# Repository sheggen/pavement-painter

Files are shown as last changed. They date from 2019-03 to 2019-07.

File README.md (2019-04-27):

# Raspberry Pi-controlled pavement painter

Pavement Painter is a Raspberry Pi controlled set of solenoids designed to print images to pavement using rain water. To use the Pavement Painter, you'll need to create the boards included in the Eagle files, as well as a few other controls. 

### WARNING:

Taking on this project is not for the faint at heart; there'll be lots of technical hiccups that you'll run into, and will have to solve on your own. There's hardware in addition to the software that you'll need to create, so get your soldering iron hot.  

## Requirements

- Raspberry Pi
- Python 3
- Everything included in requirements.txt and setup.sh (installable by running ```source setup.sh```)
- Physical boards (layouts included in the Pavement-painter directory)

## Installation

The code comes with a setup script. First do the apt-get installs listed at the beginning of the script. Then, running it should set up a Python Virtual Environment and pip install all the necessary components. Make sure the venv is activated before running the code, to ensure dependencies exist. To run the setup script, at the terminal enter ```source setup.sh```

## Usage

The code can most easily be ran at the terminal by running ```source run_at_boot.sh```. On the Pi, it is recommended that you do NOT run it using Thonny, as it causes a delay that will distort the print. At the terminal, we have yet to experience a delay in the printing outside of the physical limitations of the solenoids. 

## Modifying print parameters

Eventually parameters will be passed in through the above command. For now, though, I've placed all parameters at the ```__init__()``` method of the PavementPainter() class. Modify them and see what happens to your prints!

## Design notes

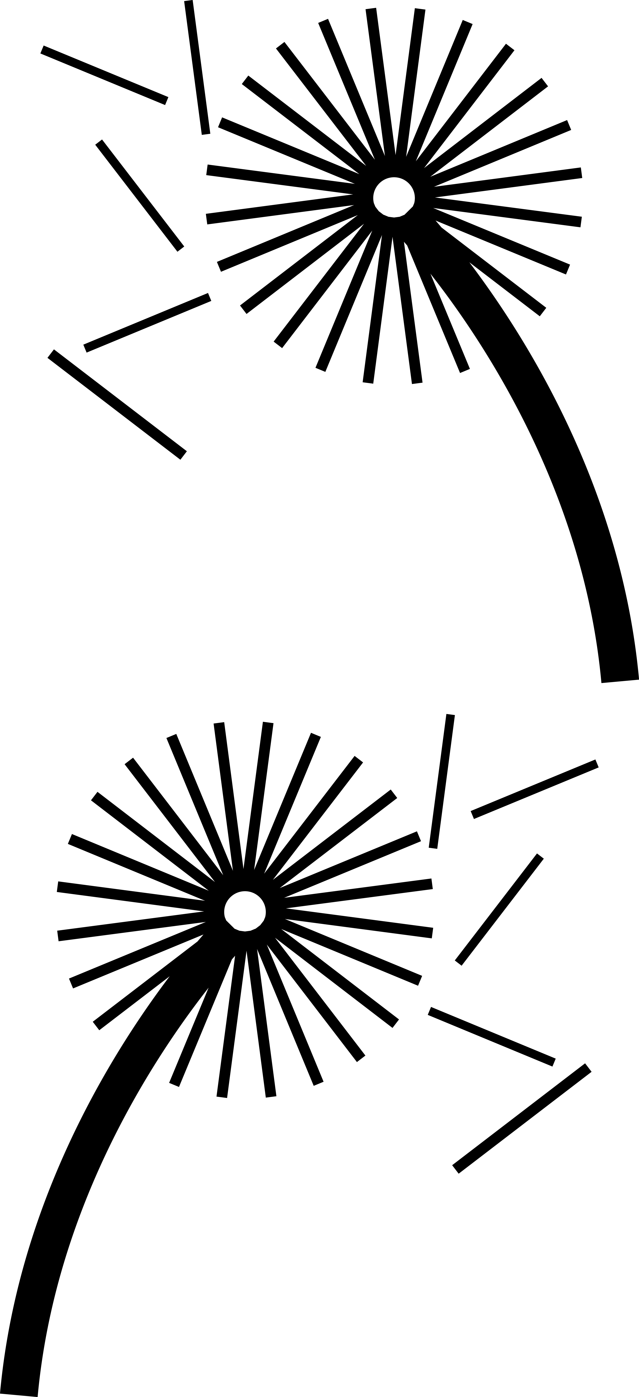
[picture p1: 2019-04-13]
webServer/app/static/images/Dandelion.jpg

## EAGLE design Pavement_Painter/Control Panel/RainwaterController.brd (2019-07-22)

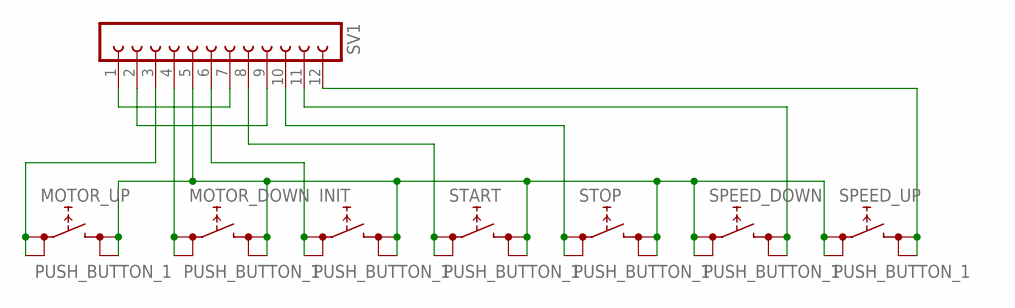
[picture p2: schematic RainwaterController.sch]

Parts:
INIT: PUSH_BUTTON_1; PUSHBUTTON
MOTOR_DOWN: PUSH_BUTTON_1; PUSHBUTTON
MOTOR_UP: PUSH_BUTTON_1; PUSHBUTTON
SPEED_DOWN: PUSH_BUTTON_1; PUSHBUTTON
SPEED_UP: PUSH_BUTTON_1; PUSHBUTTON
START: PUSH_BUTTON_1; PUSHBUTTON
STOP: PUSH_BUTTON_1; PUSHBUTTON
SV1: FE12-1; FE12

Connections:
unnamed: MOTOR_UP.P$1 (P1), MOTOR_UP.P$2 (P2), SV1.3
unnamed: SV1.1, SV1.7
unnamed: INIT.P$3 (P3), INIT.P$4 (P4), MOTOR_DOWN.P$3 (P3), MOTOR_DOWN.P$4 (P4), MOTOR_UP.P$3 (P3), MOTOR_UP.P$4 (P4), SPEED_DOWN.P$1 (P1), SPEED_DOWN.P$2 (P2), SPEED_UP.P$1 (P1), SPEED_UP.P$2 (P2), START.P$3 (P3), START.P$4 (P4), STOP.P$3 (P3), STOP.P$4 (P4), SV1.5
unnamed: SV1.2, SV1.9
unnamed: INIT.P$1 (P1), INIT.P$2 (P2), SV1.6
unnamed: START.P$1 (P1), START.P$2 (P2), SV1.8
unnamed: STOP.P$1 (P1), STOP.P$2 (P2), SV1.10
unnamed: MOTOR_DOWN.P$1 (P1), MOTOR_DOWN.P$2 (P2), SV1.4
unnamed: SPEED_DOWN.P$3 (P3), SPEED_DOWN.P$4 (P4), SV1.11
unnamed: SPEED_UP.P$3 (P3), SPEED_UP.P$4 (P4), SV1.12

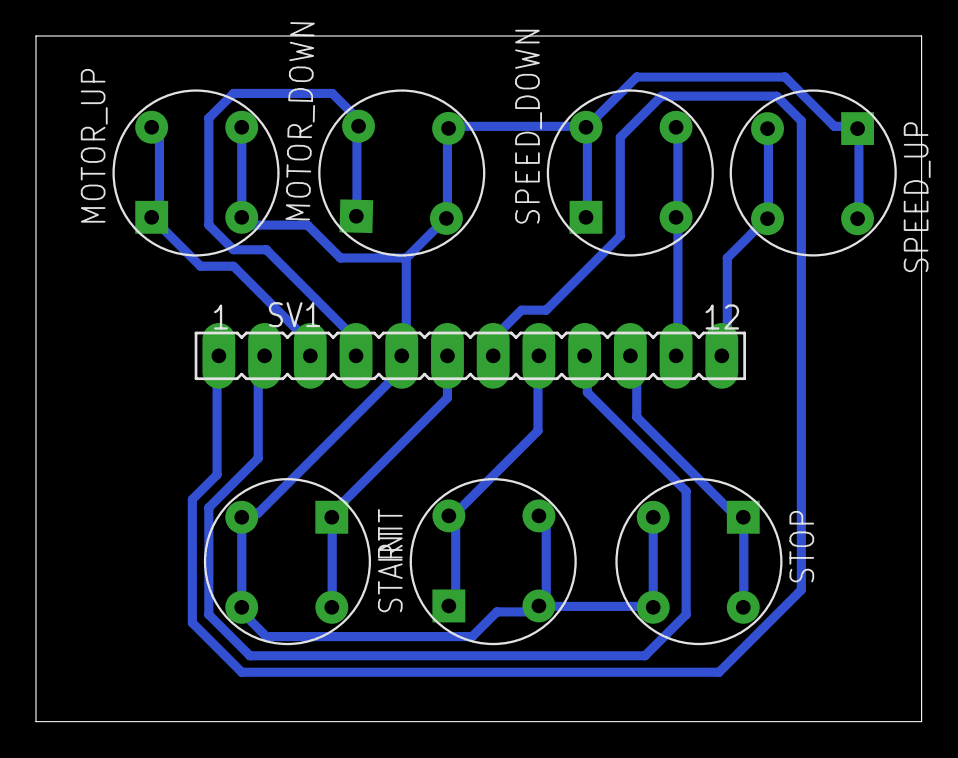
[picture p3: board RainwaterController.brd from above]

Board: 2 copper layers, 49.2 x 38.1 mm, 8 parts (0 on the bottom side), 10 nets.

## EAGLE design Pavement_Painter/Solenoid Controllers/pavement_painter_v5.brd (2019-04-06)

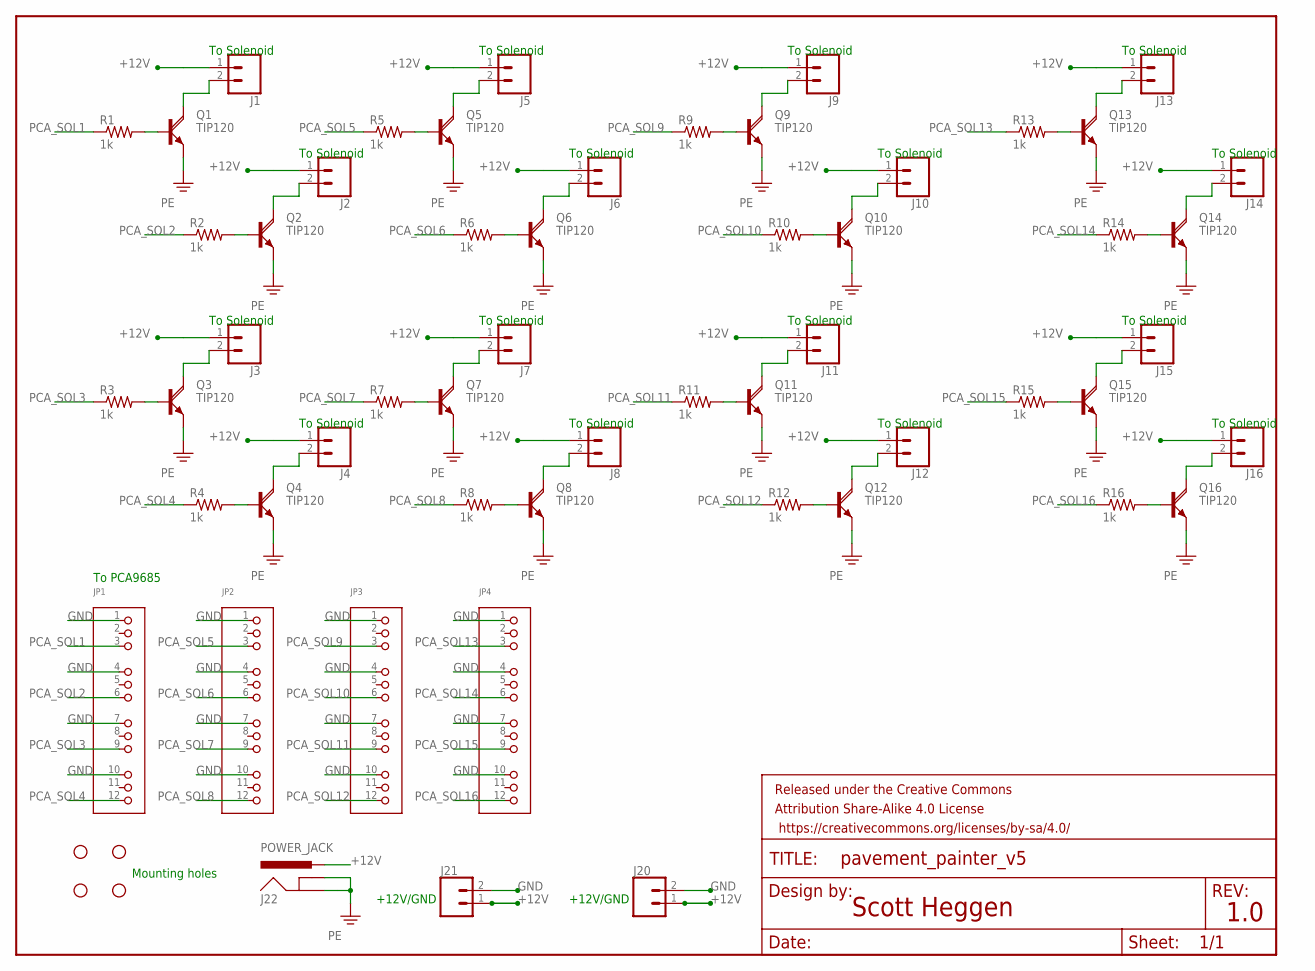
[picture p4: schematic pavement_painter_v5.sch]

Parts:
FRAME1: FRAME-LETTER; CREATIVE_COMMONS
H1, H2, H3, H4: STAND-OFF
J1, J2, J3, J4, J5, J6, J7, J8, J9, J10, J11, J12, J13, J14, J15, J16, J20, J21: CONN_02SCREWTERMINAL-200MIL-400MIL; SCREWTERMINAL-5MM-2-400MIL
J22: POWER_JACK; POWER_JACK_PTH
JP1, JP2, JP3, JP4: HEADER-3X04; 3X04
Q1, Q2, Q3, Q4, Q5, Q6, Q7, Q8, Q9, Q10, Q11, Q12, Q13, Q14, Q15, Q16: TIP120; BD679V
R1, R2, R3, R4, R5, R6, R7, R8, R9, R10, R11, R12, R13, R14, R15, R16: 1k; 0207/10

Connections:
+12V: J1.1, J2.1, J3.1, J4.1, J5.1, J6.1, J7.1, J8.1, J9.1, J10.1, J11.1, J12.1, J13.1, J14.1, J15.1, J16.1, J20.1, J21.1, J22.PWR
GND: J20.2, J21.2, J22.GND, J22.GNDBREAK, JP1.1, JP1.4, JP1.7, JP1.10, JP2.1, JP2.4, JP2.7, JP2.10, JP3.1, JP3.4, JP3.7, JP3.10, JP4.1, JP4.4, JP4.7, JP4.10, Q1.E, Q2.E, Q3.E, Q4.E, Q5.E, Q6.E, Q7.E, Q8.E, Q9.E, Q10.E, Q11.E, Q12.E, Q13.E, Q14.E, Q15.E, Q16.E
unnamed: J2.2, Q2.C
unnamed: Q2.B, R2.2
unnamed: J1.2, Q1.C
unnamed: Q1.B, R1.2
unnamed: J3.2, Q3.C
unnamed: Q3.B, R3.2
unnamed: J4.2, Q4.C
unnamed: Q4.B, R4.2
unnamed: J5.2, Q5.C
unnamed: Q5.B, R5.2
unnamed: J6.2, Q6.C
unnamed: Q6.B, R6.2
unnamed: J7.2, Q7.C
unnamed: Q7.B, R7.2
unnamed: J8.2, Q8.C
unnamed: Q8.B, R8.2
unnamed: J9.2, Q9.C
unnamed: Q9.B, R9.2
unnamed: J10.2, Q10.C
unnamed: Q10.B, R10.2
unnamed: J11.2, Q11.C
unnamed: Q11.B, R11.2
unnamed: J12.2, Q12.C
unnamed: Q12.B, R12.2
unnamed: J13.2, Q13.C
unnamed: Q13.B, R13.2
unnamed: J14.2, Q14.C
unnamed: Q14.B, R14.2
unnamed: J15.2, Q15.C
unnamed: Q15.B, R15.2
unnamed: J16.2, Q16.C
unnamed: Q16.B, R16.2
PCA_SOL1: JP1.3, R1.1
PCA_SOL2: JP1.6, R2.1
PCA_SOL3: JP1.9, R3.1
PCA_SOL4: JP1.12, R4.1
PCA_SOL5: JP2.3, R5.1
PCA_SOL6: JP2.6, R6.1
PCA_SOL7: JP2.9, R7.1
PCA_SOL8: JP2.12, R8.1
PCA_SOL9: JP3.3, R9.1
PCA_SOL10: JP3.6, R10.1
PCA_SOL11: JP3.9, R11.1
PCA_SOL12: JP3.12, R12.1
PCA_SOL13: JP4.3, R13.1
PCA_SOL14: JP4.6, R14.1
PCA_SOL15: JP4.9, R15.1
PCA_SOL16: JP4.12, R16.1

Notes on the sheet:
To Solenoid
To PCA9685
+12V/GND
Scott Heggen
1.0
Mounting holes

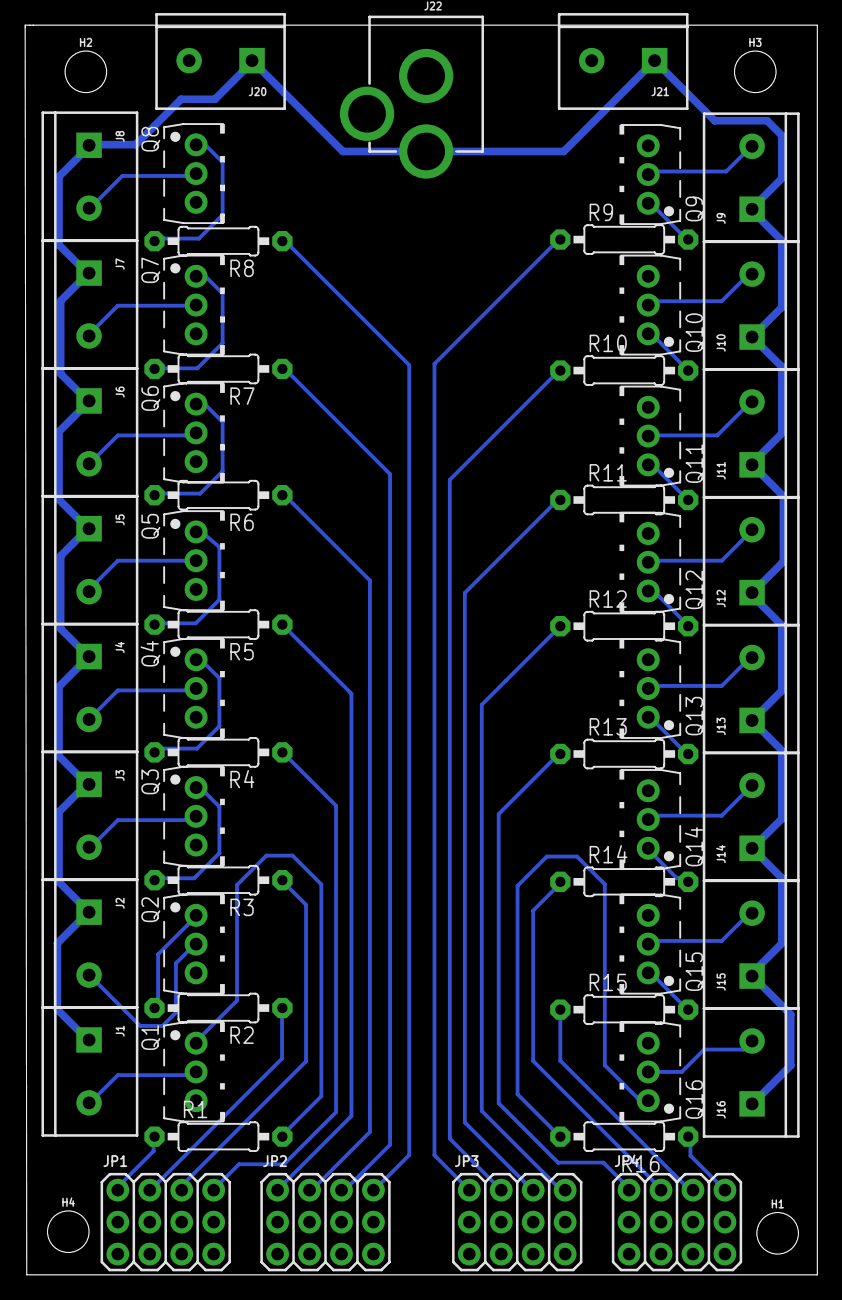
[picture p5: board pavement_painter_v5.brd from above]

Board: 2 copper layers, 63.0 x 99.3 mm, 60 parts (0 on the bottom side), 50 nets.

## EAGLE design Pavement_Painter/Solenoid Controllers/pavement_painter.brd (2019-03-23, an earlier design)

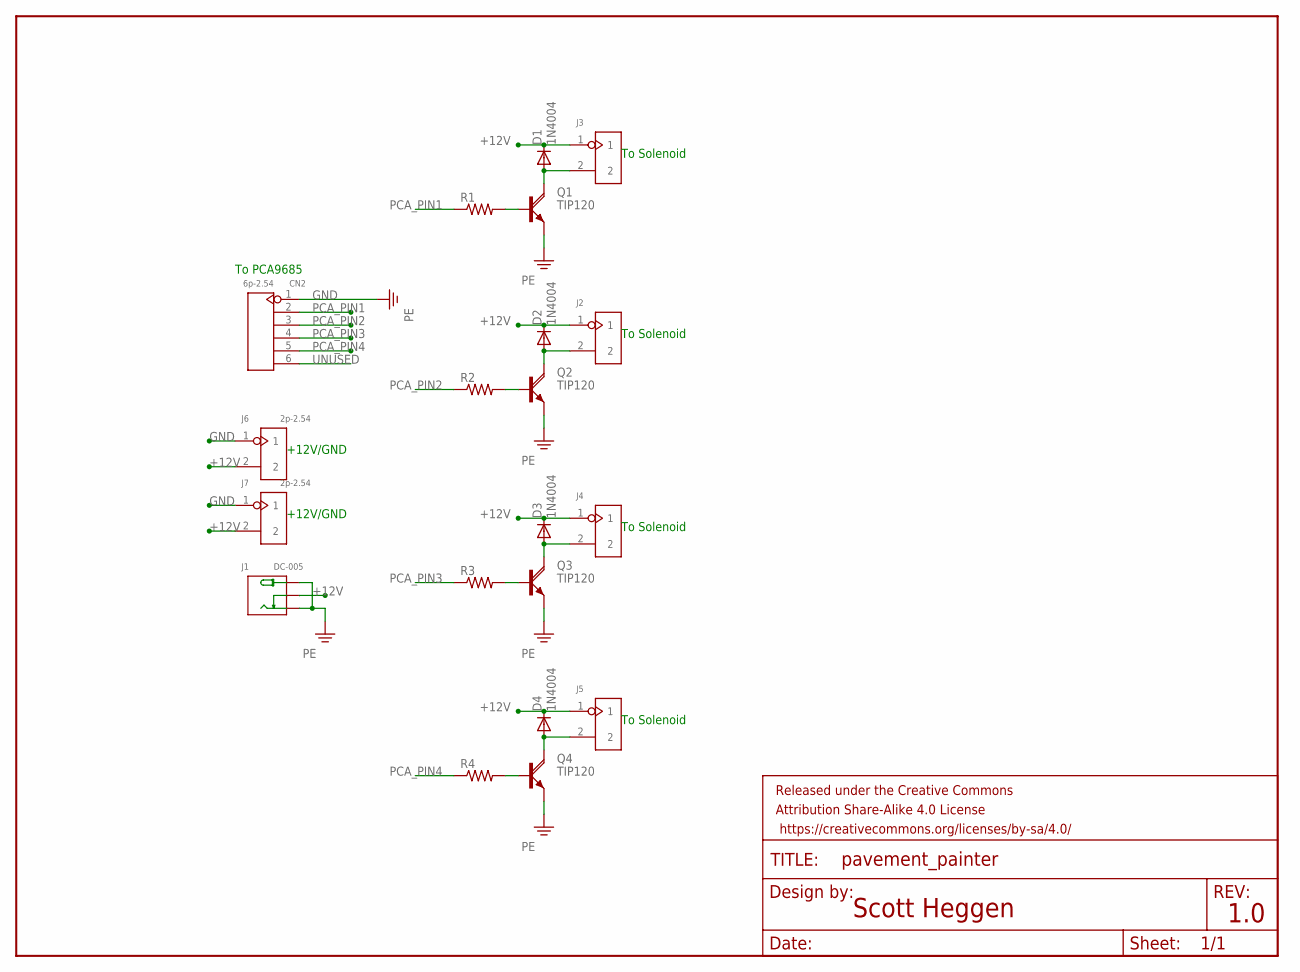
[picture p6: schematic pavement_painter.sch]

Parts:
CN2: 6p-2.54; H6-2.54
D1, D2, D3, D4: 1N4004; DO41-10
FRAME1: FRAME-LETTER; CREATIVE_COMMONS
J1: DC-005; DCJ3P-14.2X11.0X9.0MM
J2, J3, J4, J5: DIP-BLACK-JUMPER; H2-2.54
J6, J7: 2p-2.54; H2-2.54
Q1, Q2, Q3, Q4: TIP120; TO220AH
R1, R2, R3, R4: R-US_0207/12; 0207/12

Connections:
+12V: D1.C, D2.C, D3.C, D4.C, J1.-2 (CDN), J2.1, J3.1, J4.1, J5.1, J6.2, J7.2
GND: CN2.1, J1.+, J1.-1 (-), J6.1, J7.1, Q1.E, Q2.E, Q3.E, Q4.E
unnamed: D2.A, J2.2, Q2.C
unnamed: Q2.B, R2.2
unnamed: D1.A, J3.2, Q1.C
unnamed: Q1.B, R1.2
unnamed: D3.A, J4.2, Q3.C
unnamed: Q3.B, R3.2
unnamed: D4.A, J5.2, Q4.C
unnamed: Q4.B, R4.2
PCA_PIN1: CN2.2, R1.1
PCA_PIN2: CN2.3, R2.1
PCA_PIN3: CN2.4, R3.1
PCA_PIN4: CN2.5, R4.1
UNUSED: CN2.6

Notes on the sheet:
To Solenoid
To PCA9685
+12V/GND
Scott Heggen
1.0

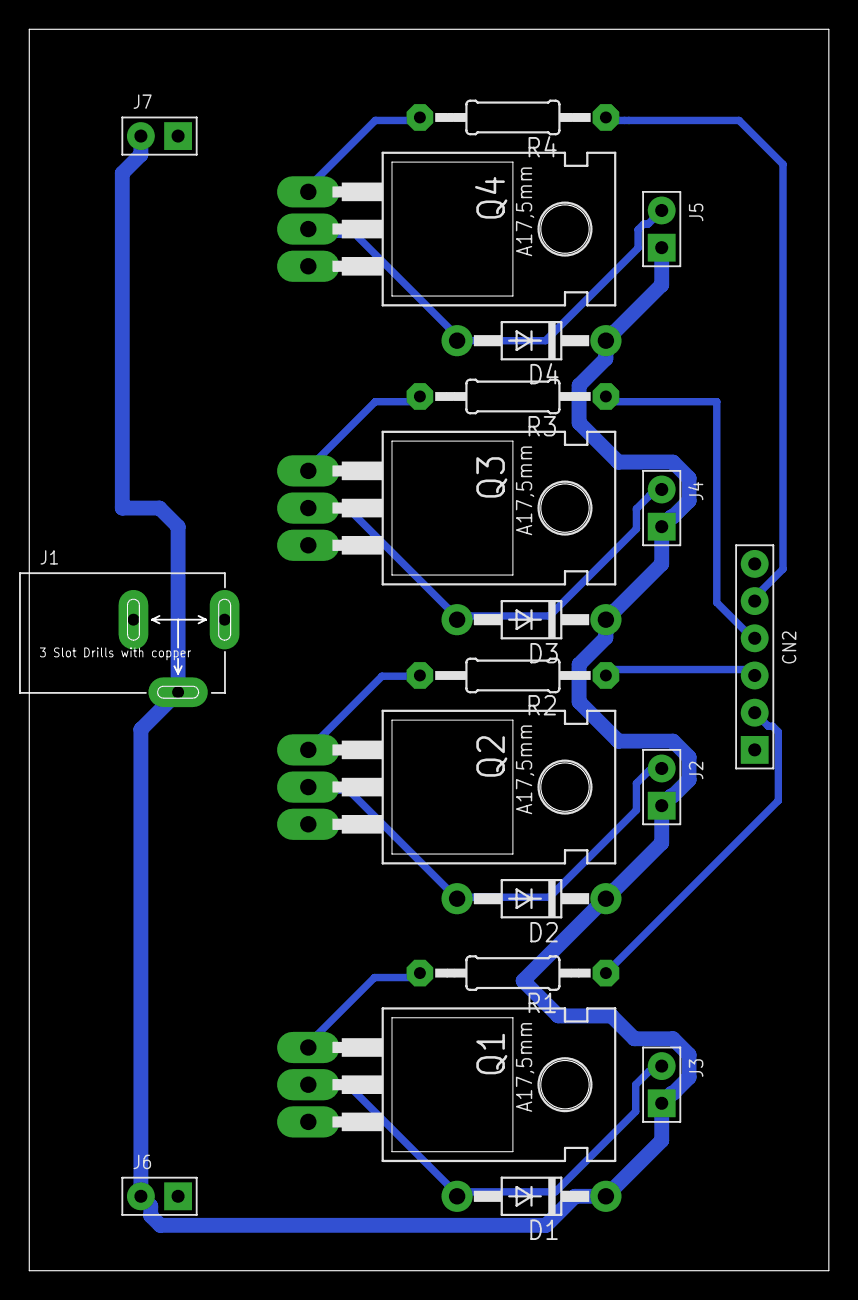
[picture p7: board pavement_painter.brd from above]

Board: 2 copper layers, 54.6 x 84.8 mm, 21 parts (0 on the bottom side), 14 nets.

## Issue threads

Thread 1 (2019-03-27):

Schematic Issues

sheggen, 2019-03-27:
Wrong footprint for J1-4, J8, J9,

J1 miswired

R's need values: 1k

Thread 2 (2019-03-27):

Layout Issues

sheggen, 2019-03-27:
Resize the board to match the PCA9685 board.

Make the board directly connect to the 4 4x3 connectors on the PCA9685 board so there's no wiring between those two boards.

Different package for power jack connector (one with large drill holes for the feet).

sheggen, 2019-04-01:
Above are all fixed in new version (v3). New problems:

Clearance around connectors to Solenoids still stinks. Better to put them all on the edge of board, even though routing will be tougher.

Power plug is directly in front of solenoid connectors. Should be fixed by above

Spacing between solenoid connectors needs closer by 13 mil if you want them to connect together. Otherwise, you can get them all on the board.

Footprint of TIP120's is too close, despite part showing having space in layout. Redesign footprint to match actual size of part (or find right package).

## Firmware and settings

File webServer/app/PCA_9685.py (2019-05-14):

from board import SCL, SDA
import busio
from Adafruit_CircuitPython_PCA9685.adafruit_pca9685 import PCA9685
import time

class PCA_9685():
    def __init__(self, num_solenoids, addr):
        """
        Creates a new PCA object

        :param num_solenoids: number of solenoids that are connected to this PCA
        :param addr: the I2C address of the PCA
        """
        self.i2c_bus = busio.I2C(SCL, SDA)
        try:
            self.pca = PCA9685(self.i2c_bus, address = addr)
            print("PCA found on: ", addr)
        except:
            print("Failed to initialize PCA on address: ", addr)
        self.pca.frequency = 1500
        self.num_solenoids = num_solenoids


    def fire_away(self, solenoid):
        """
        Activates the solenoid.

        :param solenoid: channel of the solenoid
        :return:  None
        """
        # The PCA9685 object has a channels attribute which has an object for each channel
        solenoid_channel = self.pca.channels[solenoid]
        solenoid_channel.duty_cycle = 0xffff  # fire solenoid
      
    def seize_fire(self, solenoid):
        """
        Deactivate the solenoid.

        :param solenoid: channel of the solenoid
        :return: None
        """
        solenoid_channel = self.pca.channels[solenoid]
        solenoid_channel.duty_cycle = 0x0000  # unfire solenoid


    def reset(self):
        self.pca.reset()

if __name__ == "__main__":
    x = PCA_9685(16, 0x40)
    
    while True:
        pass
        x.fire_away(3)

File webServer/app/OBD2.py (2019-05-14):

import obd
import datetime, time

class OBD2():
    """
    Handles connection to the OBD2 sensor and returns data

    """
    def __init__(self):
        # obd.logger.setLevel(obd.logging.DEBUG)
        self.fake_speed = 10 # For testing only
        self.up = True       # For testing only
        
        try:
            self.connection = obd.Async()               # auto-connects to USB or RF port
            self.connection.watch(obd.commands.SPEED)       # Watch the speed value from OBD2
            self.connection.start()
            print("Successfully connected to car")

        except:
            try:
                # Try connecting a slightly less automatic way
                self.ports = obd.scan_serial()          # return list of valid USB or RF ports
                print (self.ports)                      # ['/dev/ttyUSB0', '/dev/ttyUSB1']
                self.connection = obd.Async(self.ports[0])  # connect to the first port in the list
                self.connection.watch(obd.commands.SPEED)       # Watch the speed value from OBD2
                self.connection.start()
                print("Successfully connected to car, attempt 2")
            except:
                print("No car found")
                #self.fake_it()
        

    def get_speed(self):
        """
        Returns the speed from the OBD2

        :return: speed of the vehicle in kmph
        """
        try:
            raw_speed = self.connection.query(obd.commands.SPEED)
            # print(str(raw_speed.value).split(" ")[0])
            raw_speed_2 = int(str(raw_speed.value).split(" ")[0])
            # print(raw_speed_2)
            if raw_speed_2:
                return raw_speed_2  # non-blocking, returns immediately
        except:
            #print("Speed not found")
            return self.fake_it()
            
            
            
    def fake_it(self):
        """
        Fake the speed for testing only.
        
        return: int between 5 - 100
        """
            
        if self.fake_speed == 5 or self.fake_speed == 15:
            self.up = not self.up
        if self.up:
            self.fake_speed += 1
        else:
            self.fake_speed -= 1
        return self.fake_speed
        
            
if __name__ == "__main__":
    """
    Writes speed, date, time, and conversion to shots per second to a file
    """
    o = OBD2()
    while True:
        f = open("logger.txt", "a")
        s = str(o.get_speed())
        t = str(datetime.datetime.now())
        # print("Speed: ", s)
        f.write(t + ", " + s + ", ")
        try:
            f.write(str(9.525/(int(s.split(" ")[0])*1000/3600)))
        except:
            pass
        f.write("\n")
        f.close()
        time.sleep(1)

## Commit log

2019-03-16 Base code started; parses any image, converts to binary image, resizes to right number of solenoids, and fires them sequentially.
2019-03-21 Code appears to work; scales to any number of nozzles
2019-03-21 Bug fixes with image height and PCA needs a frequency to run LEDs at!
    [PCA_9685.py]
2019-03-22 Working on speeding up solenoid firing rata
2019-03-23 Added Eagle files
    [pavement_painter.brd, pavement_painter.sch]
2019-03-30 Updated to handle 16 solenoids on a single board, plus fixed issues with first version
    [pavement_painter_v3_larger_tolerances.brd, pavement_painter_v3_larger_tolerances.sch]
2019-04-02 Newest version with fixes from v3
    [pavement_painter_v4.brd, pavement_painter_v4.sch]
2019-04-02 Minor layout updates
    [pavement_painter_v4.brd]
2019-04-02 Layout with tighter dimension
    [pavement_painter_v4.brd]
2019-04-02 Adding code to work with ODB sensor
2019-04-04 Diodes removed, relayed out
    [pavement_painter_v5.brd, pavement_painter_v5.sch]
2019-04-04 Very minor adjustments made to layout
    [pavement_painter_v5.brd]
2019-04-06 Updating jumper numbers, slight changes to layout
    [pavement_painter_v5.brd, pavement_painter_v5.sch]
2019-04-10 Test code for OBD added; debugged firing of 45 solenoids
2019-04-13 Behind a few commits; this one worked after first road test; OBD has issues though
    [OBD2.py]
2019-04-13 Adding new files which are important, such as sample images and run_at_boot.sh
2019-04-16 incremental progress on improving printing
2019-05-12 Camera server now integrated with main code
2019-05-13 Fixed live camera to show speed
    [PavementPainter.py]
2019-05-14 Updating code with sparse matrix plus fixing speed problems
    [OBD2.py, PCA_9685.py, PavementPainter.py]
2019-05-14 Got printer running about 2.5x faster than best print, but not tested!
2019-05-21 Moving files
    [pavement_painter.brd, pavement_painter.sch, pavement_painter_v3_larger_tolerances.brd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]
2019-05-21 Removing old files
    [pavement_painter.brd, pavement_painter.sch, pavement_painter_v3_larger_tolerances.brd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]
2019-05-22 Committing Jed's files for the control panel
    [RainwaterController.brd, RainwaterController.sch]
2019-07-25 Reverting out bad imports
    [PavementPainter.py]
2019-07-30 modifying button layout
2019-07-30 adding glyphicons to buttons
2019-07-30 Webserver talking to pavement printer code now
2019-07-31 Handling button holds
2019-07-31 Adding event listeners to buttons
2019-07-31 Button listeners work with holding down
2019-07-31 Button coloring and interaction with controller working
2019-07-31 Webserver buttons work as expected now

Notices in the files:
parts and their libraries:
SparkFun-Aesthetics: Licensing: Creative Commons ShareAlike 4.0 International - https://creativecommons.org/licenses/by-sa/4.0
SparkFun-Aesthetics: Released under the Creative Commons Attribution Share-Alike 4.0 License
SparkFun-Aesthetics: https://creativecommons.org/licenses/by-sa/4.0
